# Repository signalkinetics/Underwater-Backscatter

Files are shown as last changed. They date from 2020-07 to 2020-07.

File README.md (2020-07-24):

# Underwater Backscatter

We present Piezo-Acoustic Backscatter (PAB), the first technology that enables backscatter networking in underwater environments.

Since wireless communication is the largest source of energy consumption for many underwater sensors, transitioning to
backscatter technology would eliminate the need for batteries which increase size and cost and require frequent replacement. Battery-free underwater sensors would enable us to **sense ocean conditions** (such as acidity, temperature, and bacteria content) over extended
periods of time and understand how they correlate with **climate change**. Scientists may attach these sensors to marine animals
and use them to **understand migration and habitat patterns**. Such sensors may even be **used in space missions to search for life** in the recently discovered subsurface oceans of Saturn’s moon, Titan. More generally, underwater battery-free sensors can be leveraged in
many long-term ocean applications such as **naval deployments, oil spill monitoring, and scientific exploration**

A PAB system consists of an acoustic projector (transmitter), a hydrophone (receiver), and a battery-free PAB sensor (which is essentially a piezoceramic transducer). When the projector transmits acoustic signals underwater, a PAB sensor harvests energy from these signals and powers up a microcontroller which controls the logic for backscatter. The PAB sensor then communicates by modulating the reflections of ambient sound signals. In particular, it can transmit a ‘0’ bit by absorbing the incoming energy, and a ‘1’ bit by reflecting the impinging acoustic signal. It can switch between the reflective and absorptive states by modulating the voltage across the piezoelectric interface, which in turn determines its vibration amplitude (i.e., reflection). The hydrophone receives the acoustic signals, senses changes in the amplitude due to reflection, and decodes these changes to recover the transmitted messages. In our system, we use PWM signals to trasmit data on the downlink and FM0 modulation  to send data on the uplink channel.

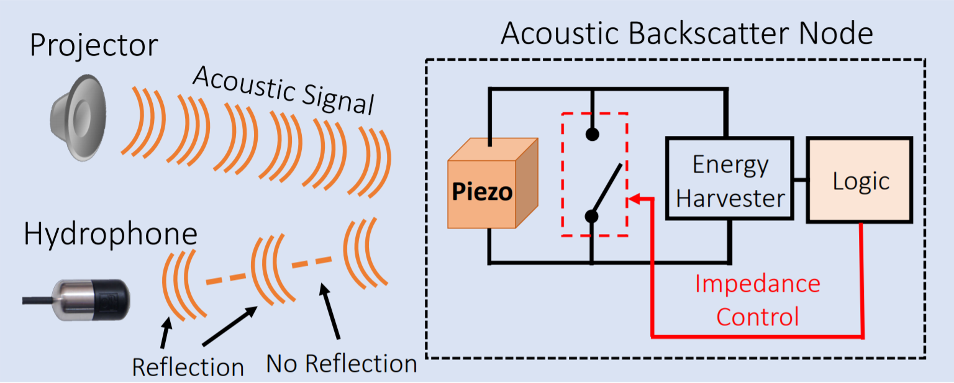
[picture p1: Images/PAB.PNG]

**PAB System Design**

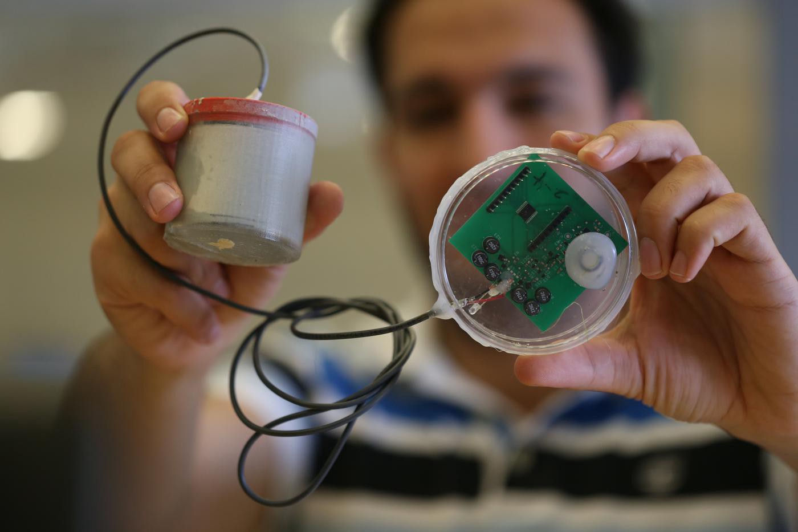
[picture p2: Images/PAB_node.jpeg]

**PAB sensor node**

# Contents

**MATLAB Rx Files/** - MATLAB code files for decoding the recieved FM0 signal.

**MATLAB Tx Files/** - MATLAB code files for transmitting a PWM acoustic signal.

**MCU code/** - C++ code for microcontroller (which controls backscatter logic).

**PCB Eagle Schematic/** - Circuit design for PCB which is connected to the PAB node.

**SolidWorks 3D Models/** - 3D printing models for mold, transducer caps and washers.

**PAB Tutorials/** - Detailed tutorials for fabricating PAB nodes and setting up the PAB system.

# Getting Started
The best way of manufacturing the PAB system is to first build the system hardware and then to work on the software part. There are several files in the "PAB Tutorials" folder which will guide you to build the system. To manufacture a PAB node, you would need a piezocermaic cylinder (we recommend ordering them from Steminc) and then 3D printing the remaining parts for assembly (SolidWorks 3D Models/). You would also need to connect wires to the inner and outer surface of the piezoceramic cylinder which will be used later to connect the PAB node to a custom made PCB with a microcontroller (PCB Eagle Schematic/). You can use the MCU code files to implement the backscatter logic in the microcontroller (MCU code/). Finally, you will need a piezoceramic transmitter and a hydrophone to transmit and receive signals respectively. We used MATLAB code to send data on the downlink and to decode the backscattered messages on the uplink (MATLAB Tx Files/, MATLAB Rx Files/)

# PAB Hardware Design
To fabricate a PAB node, you will need to get a piezoceramic cylinder and you would also need polyurethane resin (we recommend using WC-575A/B from BJP enterprise) for casting purposes. Once you have soldered wires on both sides of the piezoceramic cylinder, you would need to enclose it using 3D printed caps (with laser-cut rubber washers and screw) and then place it inside a 3D printed mold for casting (you can open the 3D models by installing the latest version of SolidWorks software). Finally you can cure the entire structure by placing it inside a pressure chamber at 4psi for at least 9 hours (see PAB tutorials for more details).

You would also need to print the PCB and populate it with all the necessary circuit components. The PCB circuit layout along with cicuit component specifications can be opened using the open source Eagle software by Autodesk (PCB Eagle Schematic/). The PCB needs to be connected to the two terminals of the potted piezoceramic cylinder node to complete the fabrication process of a PAB backscatter sensor. As a final step, you can program the MCU on the PCB by compiling the C++ code "main.c" on the microcontroller (MCU code/).

**Congratulations!** You have succesfully built a fully working, battery-free PAB sensor!

# PAB Transciever
To communicate with the PAB sensor you would need to send PWM acoustic pulses using the MATLAB code in "MATLAB Tx Files/" . To achieve this, you can simply fabricate a fully-potted piezoceramic transducer (i.e. omit the caps, washers and screws before casting) and use it as a projector. Connect the two leads of this transducer to the output of an amplifier (we recommend using Xli2500 Two-channel 750W power amplifier) and send the PWM signals by connecting the input terminals of the amplifier to a laptop using a audio jack. To deocde data on the uplink, you can simply use Audacity software to record the received sound pulses using a H2A Hydrophone and later you can decode this data offline by running "Main_Rx.m" in "MATLAB Rx Files/"

We hope that you will enjoy fabricating and deploying this PAB system in new and exciting applications. 

**Good Luck and Happy Back-scattering! :smiley:**

# Acknowledgement

**Advisor/PI:** Fadel Adib.

**Authors:** Sayed Saad Afzal, Osvy Rodriguez, Reza Gaffarivardavagh.

**Collaborators:** JunSu Jang, Jose Muguira Iturralde.

**For in-depth information on how PAB works:** 

Paper: [**Underwater Backscatter Networking**](https://www.media.mit.edu/projects/oceans/overview/), JunSu Jang and Fadel Adib [*ACM SIGCOMM'19*](https://conferences.sigcomm.org/sigcomm/2019/), Beijing, China, August 2019.

Demo Video: [Taking our ocean's pulse: Underwater Backscattering Networking](https://www.youtube.com/watch?v=zC3HaY6YJLY)

Presentation Video: [SIGCOMM 2020 talk](https://dl.acm.org/ft_gateway.cfm?id=3342091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)

# Citation
```
@incollection{jang2019underwater,
  title={Underwater backscatter networking},
  author={Jang, Junsu and Adib, Fadel},
  booktitle={Proceedings of the ACM Special Interest Group on Data Communication},
  pages={187--199},
  year={2019}
}

@incollection{gaffarivardavagh2020ultra-wideband,
  title={Ultra-Wideband Underwater Backscatter via Piezoelectric Metamaterials},
  author={Gaffarivardavagh, Reza and Afzal, Sayed Saad and Rodriguez, Osvy and Adib, Fadel},
  booktitle={Proceedings of the ACM Special Interest Group on Data Communication},
  year={2020}
}

```

Shield: [][cc-by-nc-sa]

This work is licensed under a
[Creative Commons Attribution-NonCommercial-ShareAlike 4.0 International License][cc-by-nc-sa].

[][cc-by-nc-sa]

[cc-by-nc-sa]: http://creativecommons.org/licenses/by-nc-sa/4.0/
[cc-by-nc-sa-image]: https://licensebuttons.net/l/by-nc-sa/4.0/88x31.png
[cc-by-nc-sa-shield]: https://img.shields.io/badge/License-CC%20BY--NC--SA%204.0-lightgrey.svg

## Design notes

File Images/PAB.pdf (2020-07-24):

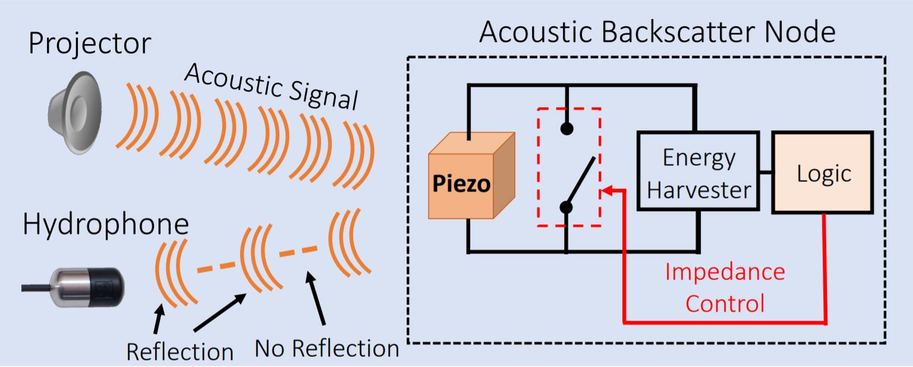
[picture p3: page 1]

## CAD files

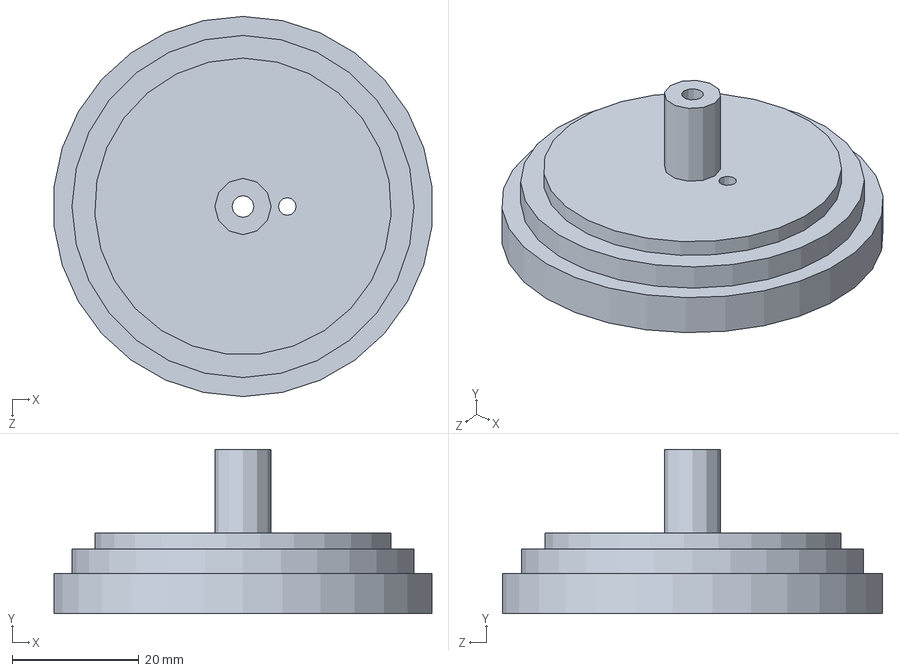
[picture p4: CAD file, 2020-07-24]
SolidWorks 3D Models/Transducer_Base_Single_Ring_For_Printing.SLDPRT
59.7 x 25.9 x 60.0 mm

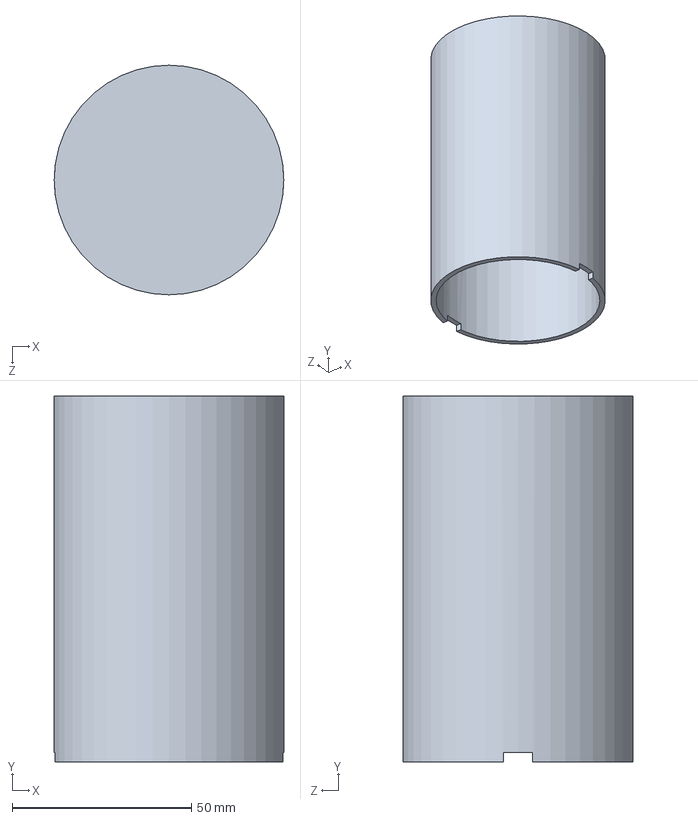
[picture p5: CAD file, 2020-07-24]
SolidWorks 3D Models/Mold_mod.SLDPRT
64.0 x 102.0 x 64.0 mm

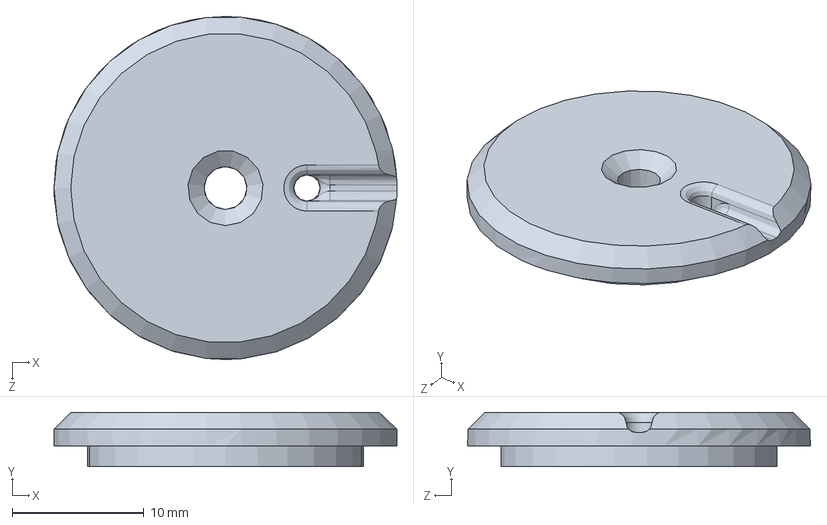
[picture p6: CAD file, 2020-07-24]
SolidWorks 3D Models/Transducer_Cap (1).SLDPRT
26.0 x 4.13 x 26.0 mm

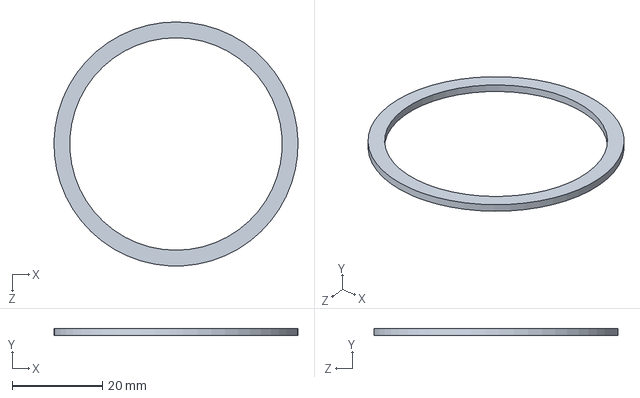
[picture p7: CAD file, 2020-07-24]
SolidWorks 3D Models/Washer.SLDPRT
54.0 x 1.59 x 54.0 mm

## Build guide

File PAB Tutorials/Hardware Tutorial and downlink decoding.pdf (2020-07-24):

Hardware Tutorial:

1- Energy Harvesting Unit

Let’s start by building the harvesting unit which is composed of two main parts the voltage multiplier and a supercapacitor to store the energy. The output of the voltage multiplier is a DC rectified and multiplied version of the incoming signal. In our design we used a fourstage voltage multiplier with this architecture.

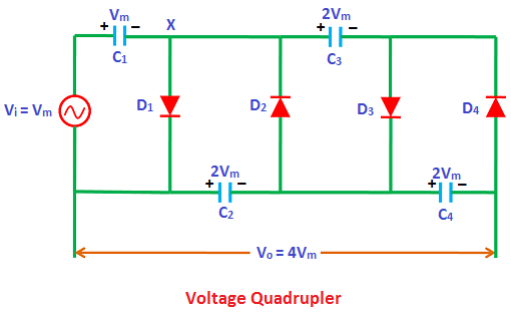
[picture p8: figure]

Fig1: Single ended voltage multiplier

Link for more information on voltage multipliers: https://www.physics-and-radio-electronics.com/electronic-devices-andcircuits/rectifier/voltagemultipliers-voltagedoubler-tripler-quadrupler.html (https://www.physics-and-radio-electronics.com/electronic-devices-and-circuits/rectifier/voltagemultipliers-voltagedoubler-tripler-quadrupler.html)

Note1: The DC voltage at the output of the voltage regulator is given by:

Vo = N*(Vmax-Vth)

Where N is the number of stages of the voltage multiplier (4 in our case), Vmax is the amplitude of the incoming signal, and Vth is the threshold voltage of the diodes being used.

Note2: The DC output of the voltage multiplier can be negative or positive depending on the orientation of the diodes.

Note3: The voltage multiplier acts as an envelope detector (low-pass filter); thus, when transmitting a PWM signal the output of the voltage regulator will look like the envelope of a sinusoidal signal that turns on and off. Like in the image below. If lower capacitances in the voltage multiplier are used the discharging time can be decreased; however, this will also cause a small ripple to appear.

Note4: The schematic in Fig.1 shows a single ended voltage multiplier for simplicity. However, since the output of the piezo electric is differential in our circuit design, we have a differential voltage multiplier which also includes a mirror image of the schematic in Fig1. (You will find the full architecture in our PCB layout)

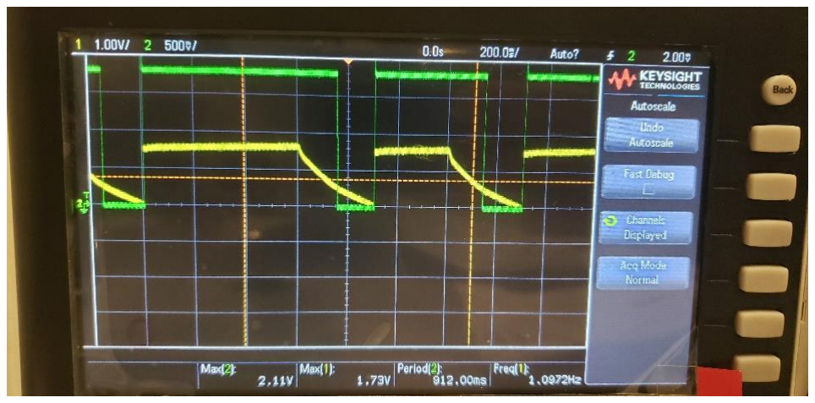
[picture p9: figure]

Fig2: Yellow curve is the PWM signal after the voltage regulator. Green curve is the Schmitt triggered version of the yellow signal.

Connect the output of the rectifier to the supercapacitor (10000 pF) via two diodes in series like the image below.

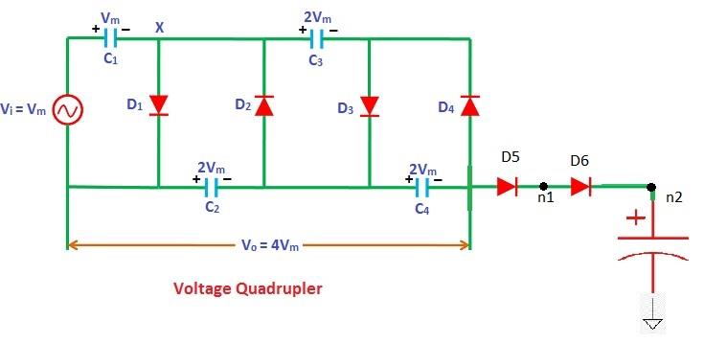
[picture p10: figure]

2- Downlink Decoder

The decoder in our circuit is composed by a level shifter (TXB0302) fig4, which incorporates a Schmitt Trigger, and a pull-down resistor that is turned on by the MCU(MSP430G2553) when decoding is desired. This part of the circuit converts the output of the PWM signal into a nice clean square wave that can be decoded by the MCU. The reason for the pull-down resistor is to fasten the discharging time of the voltage regulator’s capacitors and improve

SNR. The level shifter shifts the signal to a point where that can be detected for the MCU. The output of the level shifter is the green curve in fig2.

Note1: The used MCU incorporates a Schmitt trigger at its input; thus, we could have used only a level shifter.

Note2: The level shifter output is shifted up to the voltage fed into VccB

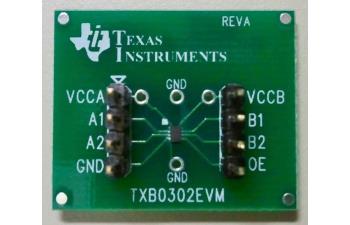
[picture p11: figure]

Fig4: Level shifter TXB0302

Connections:

The level shifter is connected to the rest of the circuit as follows. The junction between diodes D5 and D6 is connected to both VccA and A1. VccB is connected to the output of the voltage regulator. B1 is the output of the level shifter so it is connected the pin 1.1 of our MCU. The OE pin is connected to any pin of our MCU that outputs a constant voltage when it is on and ready to decode. Finally, GND is connected to ground.

Note: The output enable should also be connected to GND via a 47Kohm resistor as suggested by Texas Instruments.

3- Voltage Regulator:

A voltage regulator is needed in our circuit in order to drive the MCU and level shifter with a constant and stable voltage. The voltage regulator used was a lp5900sd(1.8V) because we want to exploit our MCU capability to operate when driven at its minimum voltage of 1.6V.

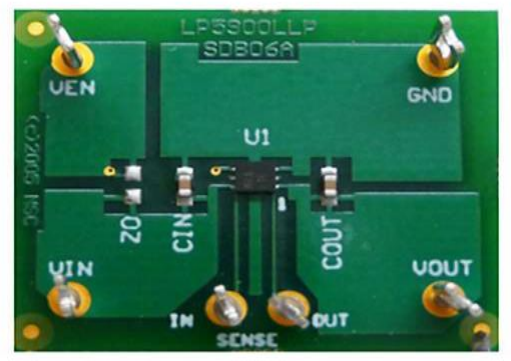
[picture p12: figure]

Fig5: lp5900SD

Connections:

The voltage regulator is connected to the rest of the circuit as follows. Ven and Vin are both connected to the positive end of the supercapacitor. Vout is connected to the VccB pin of the level shifter and to the 3.3V pin of our MCU. Finally, GND is connected to ground.

Note1: Vout and Vin both need a 0.47nF bypass capacitor as described in the image below.

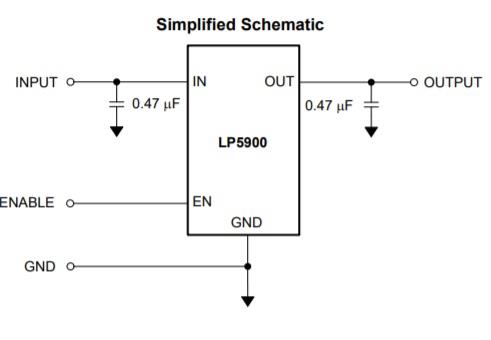
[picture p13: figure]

Fig6: LP5900 connections

Note2: If the Ven is higher than 1.2 V the LP5900 will activate and it will saturate at approximately 1.8V when the Vin reaches values higher than 1.8V.

4- Backscatter switches:

Note1: The backscatter switches consist of two N-channel MOSFETs connected in series sharing a common ground. Their sources are connected to each other and to ground. Their gates are connected to the same pin of the MCU (pin 1.0) which turns them on and off. Switching between reflective and absorptive state. The drain of each MOSFET is connected to one terminal of the piezo.

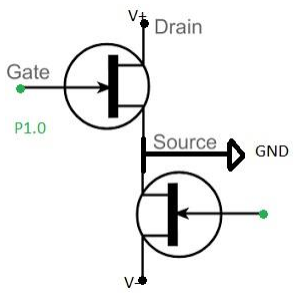
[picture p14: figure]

5- Impedance Matching Network:

The piezo electric source has a characteristic impedance. Thus, in order to ensure maximum power transfer to our circuit we added an impedance matching network. We used an L shape network composed by only inductors and capacitors. We used the E4990A Impedance analyzer to measure the impedance of the source and load.

The PCB design is shown below:

PCB layout link:

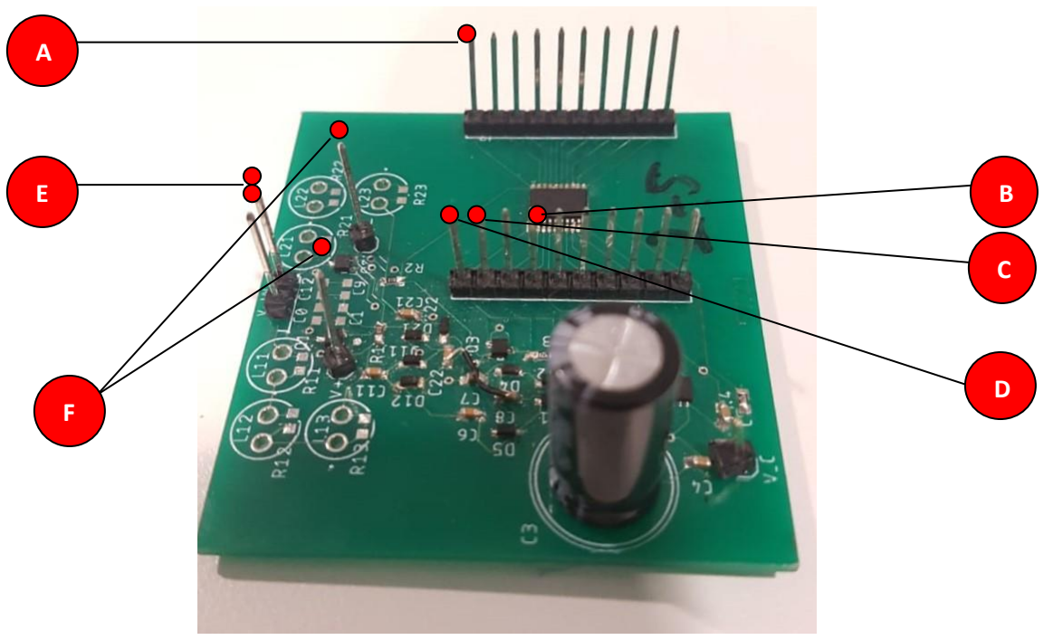
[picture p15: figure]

Note that the PCB does not include the impedance matching circuit, but still the PCB can power up the MCU and control the switching of MOSFETs if the super-capacitor can charge up to at least 2.5V from the differential PWM input signal.

The details for inputs and outputs are given below:

A

B

C

D

E

F

This pin is the common ground for the entire PCB. Use this pin as a reference when measuring voltages across different components using oscilloscope.

This pin will receive the envelop of the PWM signal in the form of a square wave which is the output of the level-shifter. If this pin shows a different waveform then check the level shifter and see if it is working properly.

This pin will output the signal which will control the switching of mosfets. The output of this pin depends entirely on the decoding algorithm in the MCU and also on the input from pin “B”

This pin is the VCC input to the MCU. If the voltage on this pin is lower than 1.8V then the MCU will not power up.

These set of pins will be used to input the differential PWM signal from the piezoelectric device. Use these pins only after you have populated the PCB will all the components which are required for impedance matching

These set of pins can also be used to input the differential PWM signal. You can use these pins even if you don’t have the impedance matching circuit

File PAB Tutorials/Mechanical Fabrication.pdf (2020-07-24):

Mechanical Fabrication of Nodes:

What you will need:

1- Steminc ceramic cylinder
2- Pressure pot
3- PLA printing material
4- polyurethane WC-575A mixture from BJB enterprises 5- Rubber sheet
6- Screws and nuts
7- Access to 3D printer, soldering station, laser cutter

The main component of our transducer is a piezoelectric cylinder. We purchased a ceramic cylinder (fig. 1) from Steminc with an in-air resonance frequency of 17 kHz, a radius of 2.5 cm, and a length of 4 cm.

Purchase link :https://www.steminc.com/PZT/en/piezo-ceramic-cylinder-541x47x40mm-17-khz

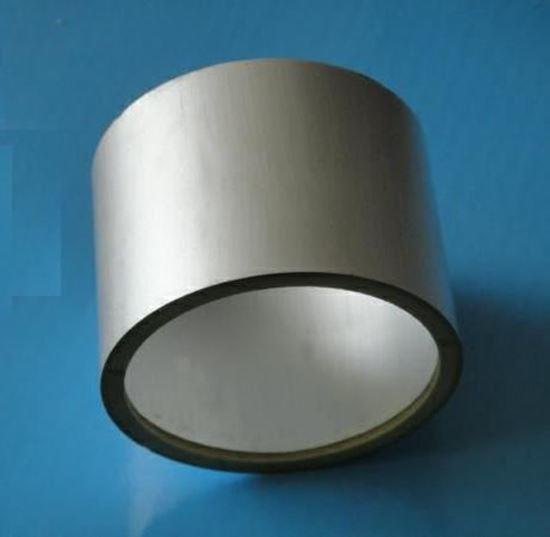
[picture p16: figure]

Fig. 1 Ceramic cylinder

Procedure:

1- First, we soldered two wires to the two electrodes of the piezoelectric ceramic (i.e., the inner and outer surfaces of the cylinder) as represented below.

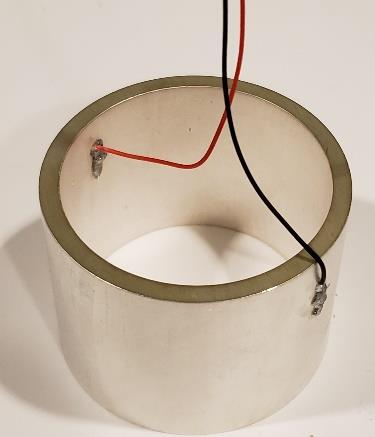
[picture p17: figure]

Fig. 2

2- We 3D printed the base and the top cap from as well as a cylindrical mold to house the ceramic cylinder and encapsulation polymer.

Add the models for 3d printing

3-Then, we laser cut rubber washers and placed them on the top and bottom of the cylinder, then placed it on a base and added a top cap.

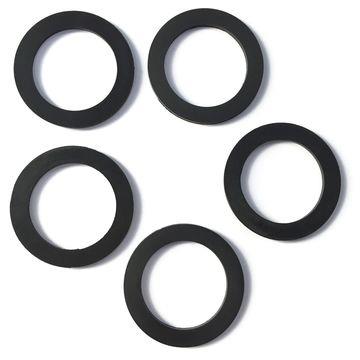
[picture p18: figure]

Fig3. Rubber washers

4- The setup is held tight using a screw and locking nut, then placed inside the mold.

Link for screws and nuts:
https://www.homedepot.com/p/Everbilt-M3-5-Stainless-Steel-Metric-Hex-Nut-2-Piece-per-Bag-842318/204836105 (https://www.homedepot.com/p/Everbilt-M3-5-Stainless-Steel-Metric-Hex-Nut-2-Piece-per-Bag-842318/204836105)

https://www.homedepot.com/p/Everbilt-M3-0-5-x-20-mm-Phillips-Pan-Head-Stainless-Steel-Machine-Screw-2-Pack-842738/204283765 (https://www.homedepot.com/p/Everbilt-M3-0-5-x-20-mm-Phillips-Pan-Head-Stainless-%20%20Steel-Machine-Screw-2-Pack-842738/204283765)

5- Finally, we prepared the encapsulation polymer, we used the polyurethane WC-575A/B mixture from BJB enterprises. The mix ratio by volume is A-100 B-94. We placed the mixture in a pressure pot at 60 (4atm) psi for at least 9 hours.

Pressure pot link: https://www.smooth-on.com/products/pressure-chamber/

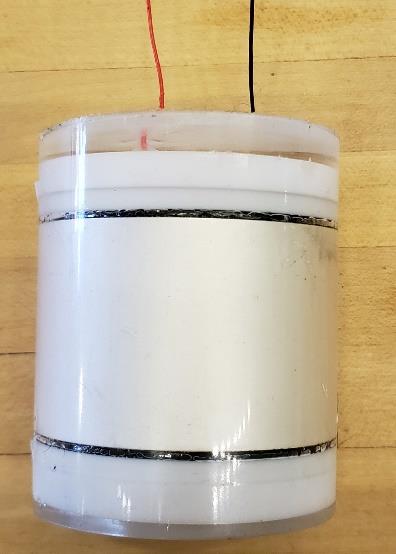
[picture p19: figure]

Fig 4. Final result

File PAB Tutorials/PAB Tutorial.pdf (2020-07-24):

# Underwater Backscatter Networking Tutorial

Mechanical Fabrication of Nodes:

What you will need:

1- Steminc ceramic cylinder
2- Pressure pot
3- PLA printing material
4- polyurethane WC-575A mixture from BJB enterprises 5- Rubber sheet
6- Screws and nuts
7- Access to 3D printer, soldering station, laser cutter

The main component of our transducer is a piezoelectric cylinder. We purchased a ceramic cylinder (fig. 1) from Steminc with an in-air resonance frequency of 17 kHz, a radius of 2.5 cm, and a length of 4 cm.

Purchase link :https://www.steminc.com/PZT/en/piezo-ceramic-cylinder-541x47x40mm-17-khz


Fig. 1 Ceramic cylinder

Procedure:

1- First, we soldered two wires to the two electrodes of the piezoelectric ceramic (i.e., the inner and outer surfaces of the cylinder) as represented below.

Fig. 2


2- We 3D printed the base and the top cap from as well as a cylindrical mold to house the ceramic cylinder and encapsulation polymer.

3-Then, we laser cut rubber washers and placed them on the top and bottom of the cylinder, then placed it on a base and added a top cap.


Fig3. Rubber washers

4- The setup is held tight using a screw and locking nut, then placed inside the mold.

Link for screws and nuts:

https://www.homedepot.com/p/Everbilt-M3-5-Stainless-Steel-Metric-Hex-Nut-2-Piece-per-Bag-842318/204836105 (https://www.homedepot.com/p/Everbilt-M3-5-Stainless-Steel-Metric-Hex-Nut-2-Piece-per-Bag-842318/204836105)

https://www.homedepot.com/p/Everbilt-M3-0-5-x-20-mm-Phillips-Pan-Head-Stainless- Steel-Machine-Screw-2-Pack-842738/204283765 (https://www.homedepot.com/p/Everbilt-M3-0-5-x-20-mm-Phillips-Pan-Head-Stainless-%20%20Steel-Machine-Screw-2-Pack-842738/204283765)

5- Finally, we prepared the encapsulation polymer, we used the polyurethane WC-575A/B mixture from BJB enterprises. The mix ratio by volume is A-100 B-94. We placed the mixture in a pressure pot at 60 (4atm) psi for at least 9 hours.

Pressure pot link: https://www.smooth-on.com/products/pressure-chamber/

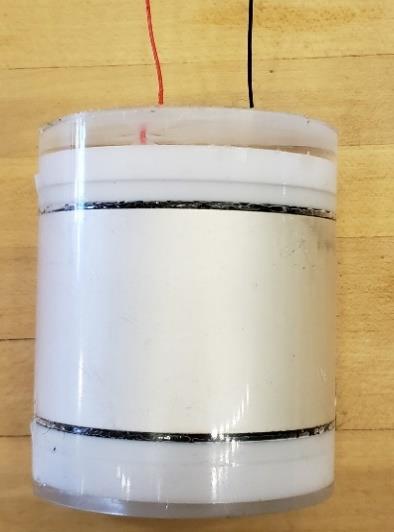
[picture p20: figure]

Fig 4. Encapsulated transducer

Hardware Tutorial

1- Energy Harvesting Unit

Let’s start by building the harvesting unit which is composed of two main parts the voltage multiplier and a supercapacitor to store the energy. The output of the voltage multiplier is a DC rectified and multiplied version of the incoming signal. In our design we used a four-stage voltage multiplier with this architecture.


Fig1: Single ended voltage multiplier

Link for more information on voltage multipliers: https://www.physics-and-radio-electronics.com/electronic-devices-and-circuits/rectifier/voltagemultipliers-voltagedoubler-tripler-quadrupler.html (https://www.physics-and-radio-electronics.com/electronic-devices-and-circuits/rectifier/voltagemultipliers-voltagedoubler-tripler-quadrupler.html)

Note1: The DC voltage at the output of the voltage regulator is given by:

Vo = N*(Vmax-Vth)

Where N is the number of stages of the voltage multiplier (4 in our case), Vmax is the amplitude of the incoming signal, and Vth is the threshold voltage of the diodes being used.

Note2: The DC output of the voltage multiplier can be negative or positive depending on the orientation of the diodes.

Note3: The voltage multiplier acts as an envelope detector (low-pass filter); thus, when transmitting a PWM signal the output of the voltage regulator will look like the envelope of a sinusoidal signal that turns on and off. Like in the image below. If lower capacitances in the voltage multiplier are used the discharging time can be decreased; however, this will also cause a small ripple to appear.

Note4: The schematic in Fig.1 shows a single ended voltage multiplier for simplicity. However, since the output of the piezo electric is differential in our circuit design, we have a differential voltage multiplier which also includes a mirror image of the schematic in Fig1. (You will find the full architecture in our PCB layout)


Fig2: Yellow curve is the PWM signal after the voltage regulator. Green curve is the Schmitt triggered version of the yellow signal.

Connect the output of the rectifier to the supercapacitor (10000 pF) via two diodes in series like the image below.

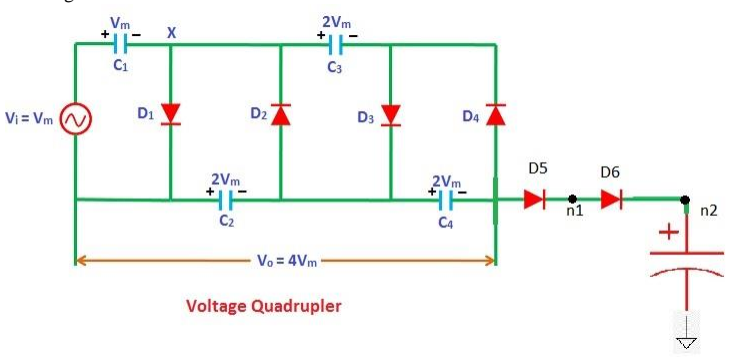
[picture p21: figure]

2- Downlink Decoder

The decoder in our circuit is composed by a level shifter (TXB0302) fig4, which incorporates a Schmitt Trigger, and a pull-down resistor that is turned on by the MCU(MSP430G2553) when decoding is desired. This part of the circuit converts the output of the PWM signal into a nice clean square wave that can be decoded by the MCU. The reason for the pull-down resistor is to fasten the discharging time of the voltage regulator’s capacitors and improve SNR. The level shifter shifts the signal to a point where that can be detected for the MCU. The output of the level shifter is the green curve in fig2.

Note1: The used MCU incorporates a Schmitt trigger at its input; thus, we could have used only a level shifter.

Note2: The level shifter output is shifted up to the voltage fed into VccB

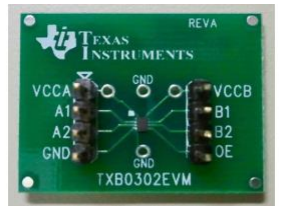
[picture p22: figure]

Fig4: Level shifter TXB0302

Connections:

The level shifter is connected to the rest of the circuit as follows. The junction between diodes D5 and D6 is connected to both VccA and A1. VccB is connected to the output of the voltage regulator. B1 is the output of the level shifter so it is connected the pin 1.1 of our MCU. The OE pin is connected to any pin of our MCU that outputs a constant voltage when it is on and ready to decode. Finally, GND is connected to ground.

Note: The output enable should also be connected to GND via a 47Kohm resistor as suggested by Texas Instruments.

3- Voltage Regulator:

A voltage regulator is needed in our circuit in order to drive the MCU and level shifter with a constant and stable voltage. The voltage regulator used was a lp5900sd(1.8V) because we want to exploit our MCU capability to operate when driven at its minimum voltage of 1.6V.


Fig5: lp5900SD

Connections:

The voltage regulator is connected to the rest of the circuit as follows. Ven and Vin are both connected to the positive end of the supercapacitor. Vout is connected to the VccB pin of the level shifter and to the 3.3V pin of our MCU. Finally, GND is connected to ground.

Note1: Vout and Vin both need a 0.47nF bypass capacitor as described in the image below.


Fig6: LP5900 connections

Note2: If the Ven is higher than 1.2 V the LP5900 will activate and it will saturate at approximately 1.8V when the Vin reaches values higher than 1.8V.

4- Backscatter switches:

Note1: The backscatter switches consist of two N-channel MOSFETs connected in series sharing a common ground. Their sources are connected to each other and to ground. Their gates are connected to the same pin of the MCU (pin 1.0) which turns them on and off. Switching between reflective and absorptive state. The drain of each MOSFET is connected to one terminal of the piezo.


The PCB design is shown below:

PCB layout link:

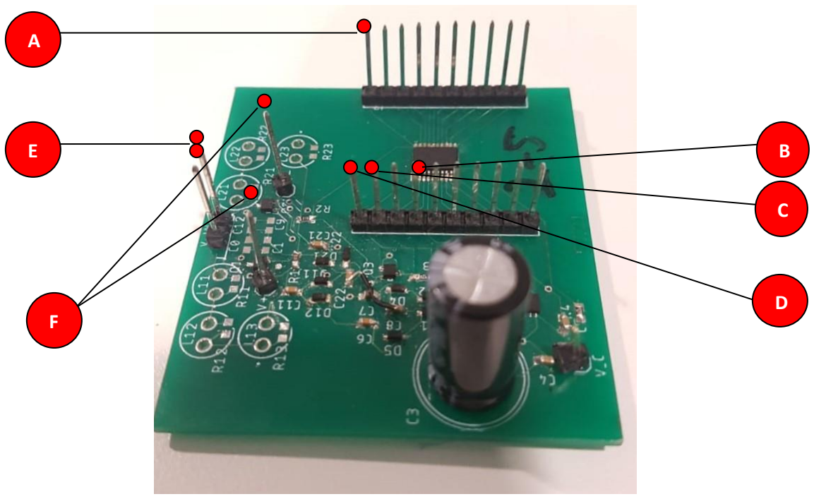
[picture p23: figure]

Note that the PCB does not include the impedance matching circuit, but still the PCB can power up the MCU and control the switching of MOSFETs if the super-capacitor can charge up to at least 2.5V from the differential PWM input signal.

The details for inputs and outputs are given below:

A

B

C

D

E

F

This pin is the common ground for the entire PCB. Use this pin as a reference when measuring voltages across different components using oscilloscope.

This pin will receive the envelop of the PWM signal in the form of a square wave which is the output of the level-shifter. If this pin shows a different waveform then check the level shifter and see if it is working properly.

This pin will output the signal which will control the switching of mosfets. The output of this pin depends entirely on the decoding algorithm in the MCU and also on the input from pin “B”

This pin is the VCC input to the MCU. If the voltage on this pin is lower than 1.8V then the MCU will not power up.

These set of pins will be used to input the differential PWM signal from the piezoelectric device. Use these pins only after you have populated the PCB will all the components which are required for impedance matching

These set of pins can also be used to input the differential PWM signal. You can use these pins even if you don’t have the impedance matching circuit

Transmitter (Tx)

What you would need:

1- Our in-house built transducer
2- Laptop or desktop computer with audio jack output 3- Xli2500 Two-channel 750W power amplifier

Note:

The transmitted signal is generated using MATLAB, we first transmit a pure sine at around 17kHz the resonant frequency of our transducer. Secondly, we employ pulse width modulation (PWM) where the ‘1’ bit is twice as long as the ‘0’ bit.

PAB (Tx) MATLAB code

%The transmission consists of two stages: energy harvesting stage and
%communication stage: During the energy harvesting stage we transmit a pure
%sinusoidal signal and during the communication stage we transmit a PWM
%that encodes 1's and 0's (being a 1 twice longer that a 0). Finally, we
%transmit again a pure sinusoidal that will be backscattered by the node.

% Generate purely sinusoidal
f = 15000; %15Khz
Fs = 44100; %Sampling frequency ts = 1/Fs;
T | = 10; % Generate 10 seconds
t | = 0:ts:T;
signal = sin(2*pi*f.*t);
%%%%%%%%%%%%%%%%%%%%%%%%

%Generate bits
preamble = [1 0 1 1 0 1 1 1 0 1 0 0 1 0 0 0 1 0 1 0]; bit1 = repmat(1,1,2*9000);
bit0 = repmat(1,1,9000);
zero = repmat(0,1,9000);

sq = [];
for bit = preamble

if bit == 1
sq = [sq bit1 zero];

elseif bit == 0
sq = [sq bit0 zero];

end
end
%modulated signal
PWM = sq(1:end-length(zero)+1).*signal; %%%%%%%%%%%%%%%%%%%%%%%%

%Charge the PAB node and then transmit preamble

sound(signal, Fs);
pause(12) %wait for 12 seconds
sound(PWM, Fs);
pause(12)
sound(signal,Fs)

Receiver (Rx)

What you would need:

1- H2A Hydrophone (Fig. 1)

2- Laptop or desktop computer with audio jack input

3- Audacity software

4- Our MATLAB decoder

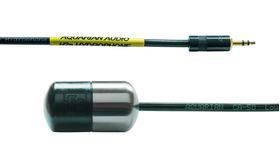
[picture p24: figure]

Fig. 1

Link:

https://www.aquarianaudio.com/h2a-hydrophone.html

https://www.audacityteam.org/

MATLAB decoder:

Our decoder identifies the different transmitted frequencies on the downlink using FFT and peak detection. It then down-converts the signals to baseband by multiplying each of them with its respective carrier frequency. The receiver then employs a Butterworth filter on each of the receive channels to isolate the signal of interest and reduce interference from concurrent transmissions. Subsequently, it performs standard packet detection and carrier frequency offset (CFO) correction using the preamble. Finally, it employs a maximum likelihood decoder to decode the FM0 decoded bits.

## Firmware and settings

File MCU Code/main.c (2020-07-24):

// Underwater Acoustic Backscatter MCU
//
// Goal: Receive and decode a known query. Upon successful
//       decoding, backscatter signal by toggling between
//       reflective and non-reflective state
//
// Communication: FM0 (varying length of reflection followed by
//                     no a period of no reflection)
//                bit 1: long reflection (2*BIT_PERIOD)
//                bit 0: short reflection (BIT_PERIOD)
//
// Pin Layout
// Pin0: Controls the transistors to control
//       reflective/non-reflective state
// Pin2: Rectified singal input whose rising edge is
//       detected every clock cycle
// Pin3: Toggling at every detected rising edge (debug)
// Pin6: Swtich on the pull-down resistor to control
//       the receiving/transmitting mode

#include <msp430.h>
#include <stdint.h>

#define QUERY_LEN 9
#define PREAMBLE_LEN 20
#define TX_LEN 32
#define HALF_CYCLE 25
#define BIT_PERIOD 500
#define QUERY_FLIP_PERIOD 3000

uint16_t bit_start = 0, gap=1;
uint16_t now, bit, i;
uint8_t rx_fifo = 0, offset = 0, query = 0b10110100, mask=0xFF;
uint32_t tx_byte;
uint32_t preamble1 = 0b10110111010010001010;
uint32_t training = 0b00000000000000000000;
uint32_t data_byte = 0b10110100101101001011010010110100;
uint32_t data_byte2 = 0b10101010101010101010101010101010;
uint32_t data_byte3 = 0b11110000110010100000111100110101;
uint32_t bit_count;
uint8_t temp, state_AB, clk, state;
int cycle;

void printf(char *, ...);
void RX_Ready (void);
void TX_Byte(void);
void Preamble_Byte (void);

inline static void Clock_init(void);
//Sets up two clocks; one normal and another low-frequency low-power clock in order to use them 
//in the different states of the MCU

int main(void)
{
     WDTCTL = WDTPW | WDTHOLD;                    // Stop WDT
     Clock_init();                                // Initialize the clocks

    // Configure GPIO
    P1DIR |= BIT0 + BIT4 + BIT3; // BIT3                 // Set pins to outputs
    P1OUT &= ~(BIT0 + BIT3);                             // piezo and load are connected
    P1OUT |=  BIT4; //BIT3                        // debug and ready to receive
    P1SEL = BIT2;                                 // Setup for clock interrupts on pin2

    TACTL = TASSEL_1 | MC_2 | TACLR;              // Sets up timer A.
												  //ACLK, continuous mode, clears timer A before starting, enable interrupt
	
												  
												  
												  
												  
	// Enter LPM3, enable interrupts

    cycle = 100;

    bit_count = PREAMBLE_LEN;
    // Send Preamble
    while (bit_count > 0) {

		for (i=0; i<cycle; i++) {};//Delays according to the cycle (in this case is 100)


		//In this piece of code you send a series of bits by toggling the device between the reflective/non-reflective states
		//You do this in a loop that last for as many bits as the preamble has.
		//BIT0 is the one in charge of toggling the device between the two modes
		//Most of the other variables are used for properly sending the desired preamble
        bit = (bit & 0) + clk & (preamble1 >> bit_count) & BIT0;
        state_AB = (((clk^(state_AB & BIT0)) & BIT0) << 1) + ((((~bit) & state_AB&BIT0)|((~clk)& state_AB&BIT0)|(clk&bit&(~(state_AB&BIT0))))&BIT0);
        temp = ((clk & BIT0) * ((state_AB & BIT1) >> 1) + ((~clk) & BIT0) * (state_AB & BIT0));
        P1OUT = (P1OUT & ~BIT0) + (temp & BIT0);
        clk = (~clk) & BIT0;
        bit_count -= clk;
    }

	//Sending another piece of information
    bit_count =200;
    while (bit_count > 0) {

        for (i = 0; i < cycle; i++) {};// Delay used according to the cycle(in this case is 100)
        bit = 1; 


        state_AB = (((clk^(state_AB & BIT0)) & BIT0) << 1) + ((((~bit) & state_AB&BIT0)|((~clk)& state_AB&BIT0)|(clk&bit&(~(state_AB&BIT0))))&BIT0);



        temp = ((clk & BIT0) * ((state_AB & BIT1) >> 1) + ((~clk) & BIT0) * (state_AB & BIT0));
        P1OUT = (P1OUT & ~BIT0) + (temp & BIT0);
        clk = (~clk) & BIT0;
        bit_count -= clk;

    }
    P1OUT &= ~BIT0;

//     sleep

}

// Set the MCU into receiving mode
void RX_Ready(void) {
    P1OUT &= ~(BIT0 + BIT1);//Puts BIT0 = 0 to toggle into receiving mode
    rx_fifo = 0;
    bit_count = 8;
    // Configure Timer_A
    TACCTL1 = SCS + CM_1 + CAP + CCIE + CCIS_0;
	//Timer A1
	//SCS = Capture Synchronize
	//CM_1 = Capture mode: 1- pos. edge
	//CAP = Capture mode: 1
	//CCIE = Capture/Compare Interrupt enable
	//CCIS_0 = Capture input select: 0 - CCIxA
}

// Set the MCU to transmitting mode
void TX_Byte(void) {
    state_AB = 0b00;
    clk = 1;
    bit_count = TX_LEN; //data    32
    tx_byte = data_byte2;//This is the transmitted data
    // Set timer interrupts
    TACCR1 = TAR + HALF_CYCLE;
    // Reconfigure Timer_A
    TACCTL1 = CM_0 + CCIE;
	//This configuration makes it not being in capture mode
	//but it has enabled interrupts in case new information is arriving
}

void Preamble_Byte(void) {
	//This function is used for transmitting the preamble
    state = 1;
    state_AB = 0b00;
    clk = 1;
    bit_count = PREAMBLE_LEN; // preamble
    tx_byte = preamble1; //training;
    // Set timer interrupts
    TACCR1 = TAR + HALF_CYCLE;
    // Reconfigure Timer_A
    TACCTL1 = CM_0 + CCIE;
}


// Timer0_A1 Interrupt Vector (TAIV) handler
#if defined(__TI_COMPILER_VERSION__) || defined(__IAR_SYSTEMS_ICC__)
#pragma vector=TIMER0_A1_VECTOR
__interrupt void TIMER0_A1_ISR(void)
#elif defined(__GNUC__)
void __attribute__ ((interrupt(TIMER0_A1_VECTOR))) TIMER0_A1_ISR (void)
#else
#error Compiler not supported!
#endif
{
    switch(__even_in_range(TA0IV,TA0IV_TAIFG))
    {
        case TA0IV_NONE:
            break;//In case of no interrupt pending just continue
        case TA0IV_TACCR1:
            // RX mode
            if(TACCTL1 & CAP) {
                now = TACCR1; // timestamp
                // we start measuring the duration of amplitude flip on the first
                // rising edge. Hence, we let the bit_count start at 9 instead of 8
                if (bit_count < 8) {
                    if ((TACCTL1 & BIT1) == 0) {
                        // Determine how long for a amplitude flip to determine bit received
                        bit = (now - bit_start) > QUERY_FLIP_PERIOD ? 1 : 0;
                        rx_fifo |= bit << bit_count;
                    } else { // There was a second capture unfortunately
                        TACCTL1 &= ~(BIT1);
                    }
                }
                // All the bits have been received
                if (bit_count == 0) {

                    // Compare the bits first
                    offset = 0;
                    while ((offset < QUERY_LEN) \
                            && ((rx_fifo & (mask >> offset)) != (query >> offset))) {
                        offset++;
                    }
                    // successful
                    if (offset == 0) {
                        P1OUT |= BIT3;
                        TACCTL1 &= ~CCIE;                  // All bits RXed, disable interrupts from capture
                        __bic_SR_register_on_exit(LPM3_bits); // CLear LPM3its to start transmitting
                    } else {
                    // failed
                        RX_Ready();
                    }
                }
                bit_count--;
                bit_start = now;
            // TX mode
            } else {
                TACCR1 += HALF_CYCLE;
                if (bit_count == 0 && clk == 1) {
                    state += 1;
                    if (state == 1) {
                        bit_count = PREAMBLE_LEN;
                        tx_byte = preamble1;
                    } else if(state == 2) {
                        bit_count = 1000; //TX_LEN;
                        tx_byte = data_byte2;
                    } else if (state > 2){
                        TACCTL1 &= ~CCIE;
                        __bic_SR_register_on_exit(LPM3_bits);
                    }
                }
                bit_count -= clk;
                if (state == 0) {
                    bit = 0;
                } else if (state == 1) {
                    bit = (bit & 0) + clk & (tx_byte >> bit_count) & BIT0;
                } else if (state == 2) {
                    bit = (bit ^ clk) & BIT0;
                }
                state_AB = (((clk^(state_AB & BIT0)) & BIT0) << 1) + ((((~bit) & state_AB&BIT0)|((~clk)& state_AB&BIT0)|(clk&bit&(~(state_AB&BIT0))))&BIT0);
                temp = ((clk & BIT0) * ((state_AB & BIT1) >> 1) + ((~clk) & BIT0) * (state_AB & BIT0));
                P1OUT = (P1OUT & ~BIT0) + (temp & BIT0);
                clk = (~clk) & BIT0;


                }
            TACCTL1 &= ~(BIT0);
            break;                               // CCR1 not used
        case TA0IV_TACCR2:
            break;                               // CCR2 not used
        case TA0IV_TAIFG:
            break;
        default:
            break;
    }

}

inline static void Clock_init(void)
{
    BCSCTL1 = CALBC1_1MHZ;              // Set Digitally Controlled Oscillator (DCO) to default of 1Mhz
    DCOCTL = CALDCO_1MHZ;			    // Set the DCO Register to 1 Mhz  (step & modulation)

    BCSCTL3 = LFXT1S_2;                // LFXT1 = VLO (Very Low-Power Low-Frequency Oscillator). Clock that uses little energy for functioning and no energy when off.
    IFG1 &= ~(OFIFG);                   // Clear OSCFault flag (Interrupt Flag Register)
}

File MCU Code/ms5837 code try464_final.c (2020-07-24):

//******************************************************************************
//  MSP430G2553 USCI_B0 I2C connection to ms5837-30BA 
//  ACLK = n/a, MCLK = SMCLK = BRCLK = default DCO = ~1.0MHz
//
//
//                                /|\  /|\
//                  MS5837        10k  10k   MSP430G2553
//                   slave         |    |      master
//             -----------------   |    |  -----------------
//            |       SDA       |<-|---+->|P1.7/UCB0SDA  
//            |                 |  |      |                 
//            |                 |  |      |             
//            |       SCLK      |<-+----->|P1.6/UCB0SCL     
//            |                 |         |                 
//
//******************************************************************************
#include <msp430.h>
#include <stdint.h>

#define NUM_BYTES_TX 1                  		
// FUNCTION RETURN VALUES
#define RET_SUCCESS		0
#define RET_FAIL			1
#define RET_FAIL_CALIB		4
#define RET_TIMEOUT		5

volatile int RXByteCtr, i;    	
volatile unsigned char RxBuffer[22];  			// Allocate 22 bytes of RAM
volatile int Rx_idx=0, Tx_idx=0;
volatile char TXByteCtr, RX = 0;
volatile char MSData[13]={0x1E,0xA0,0xA2,0xA4,0xA6,0xA8,0xAA,0xAC,0x4A,0,0x5A,0,0};
volatile char ret, receivedCrc, calculatedCrc;
volatile unsigned short buff[8];
volatile int NUM_BYTES_RX = 2;				// Received bytes = 2 for prom
volatile unsigned short sensorC[7];
volatile signed long D1=0, D2=0, dT, TEMP, PRESSURE; 
volatile signed long long SENS, pressure, temp, OFF;

void Setup_TX(void);
void Setup_TX1(void);
void Setup_RX(void);
void Transmit(void);
void Receive(void);
char unlockI2Cline(unsigned short maxLoops);
char isMS5837Available();
unsigned char crc4(volatile unsigned short n_prom[]);  


int main(void)
{
 	WDTCTL = WDTPW + WDTHOLD;              		// Stop WDT

	// Initialize P2 for ms5837 status
	P2DIR |= BIT0;                   				// P2.0 output
	P2OUT &= ~BIT0;							// Set P2.0 to low

  	P1SEL |= BIT6 + BIT7;                 		// Assign I2C pins to USCI_B0
  	P1SEL2|= BIT6 + BIT7;                  		// Assign I2C pins to USCI_B0
    
  	//Transmit process
  	Setup_TX(); 
  	Transmit(); 
	__delay_cycles(100000);  				// 100ms,Make sure reset done
  	while (UCB0CTL1 & UCTXSTP);

	for (i=0;i<7;i++)
	{	
  		Tx_idx++;
		Setup_TX1(); 
  		Transmit(); 
  		while (UCB0CTL1 & UCTXSTP);    			// Ensure stop condition got sent

  		//Receive process
  		Setup_RX();	
  		Receive();	
		__delay_cycles(10000);
  		while (UCB0CTL1 & UCTXSTP);     		// Ensure stop condition got sent
	}

	for (i=0;i<7;i++)
	{ 
		buff[i] = (RxBuffer[i*2]<<8) + RxBuffer[i*2+1]; 
		sensorC[i] = buff[i];
	}
	buff[7] = 0x0000;
	receivedCrc = ((buff[0] >> 8) >> 4) & 0x0F;	// Read received CRC
	calculatedCrc = crc4(buff);
	if(calculatedCrc != receivedCrc) ret = 33; 	// Compare with calculated CRC-4
	
	NUM_BYTES_RX = 3;
	for (i=0;i<2;i++)
	{	
  		Tx_idx++;
		Setup_TX1(); 
  		Transmit(); 
  		while (UCB0CTL1 & UCTXSTP);    		// Ensure stop condition got sent
		__delay_cycles(30000);		// ADC conversion > 18.08ms

		Tx_idx++;
		Setup_TX1(); 
  		Transmit(); 
  		while (UCB0CTL1 & UCTXSTP);    		// Ensure stop condition got sent

  		//Receive process
  		Setup_RX();	
  		Receive();	
		__delay_cycles(10000);
  		while (UCB0CTL1 & UCTXSTP);     	// Ensure stop condition got sent
	}
	
	__disable_interrupt();
	D1 = (signed long)RxBuffer[14]*256*256+ (signed long)RxBuffer[15]*256+ (signed long)RxBuffer[16];
	D2 = (signed long)RxBuffer[17]*256*256+ (signed long)RxBuffer[18]*256+ (signed long)RxBuffer[19];

	// Calculate compensated temperature and pressure
	dT = D2 - ((signed long)sensorC[5] * 256);
	OFF = ((signed long long)sensorC[2] * 65536) + (((signed long long)sensorC[4] * (signed long long) dT)/128);
	SENS = ((signed long long)sensorC[1] * 32768) + (((signed long long)sensorC[3] * (signed long long) dT)/256);
	temp = 2000 + ((signed long long)dT * (signed long long)sensorC[6])/8388608;
	TEMP = temp;
	pressure = (((signed long long)D1 * SENS / 2097152) - OFF) / 8192;
	PRESSURE = pressure;

	// If CRC correct AND 10degC < temperature < 30degC
	// AND 0.9bar < pressure < 2.1 bar (11m depth water)
	// toggle p2.0 at 1Hz for 5 times, otherwise p2.0 kept logic 0

	if ((receivedCrc == calculatedCrc) && (TEMP<3000 && TEMP>1000) && (PRESSURE<21000 && PRESSURE>9000)) 
	{	
		for (i=0;i<5;i++)
		{
			P2OUT |= BIT0 + BIT1;		// results correct
			__delay_cycles(500000);  		// p2.0 = 1 for 0.5s 
			P2OUT &= ~BIT0; P2OUT &= ~BIT1;	
        __delay_cycles(500000);  		// p2.0 = 0 for 0.5s
		}
	}	
	else P2OUT &= ~BIT0;			// ms5837 failed

	while(1){ __delay_cycles(100000);}		// put breakpoint here
}


unsigned char crc4(volatile unsigned short n_prom[])  
{
	int cnt; // simple counter
	unsigned int n_rem=0; 		// crc remainder
	unsigned char n_bit;
	n_prom[0]=((n_prom[0]) & 0x0FFF); 		// CRC byte is replaced by 0
	n_prom[7]=0;  				// Subsidiary value, set to 0
	for (cnt = 0; cnt < 16; cnt++) 		// operation is performed on bytes
	{ // choose LSB or MSB
		if (cnt%2==1) n_rem ^= (unsigned short) ((n_prom[cnt>>1]) & 0x00FF);
		else n_rem ^= (unsigned short) (n_prom[cnt>>1]>>8);
		for (n_bit = 8; n_bit > 0; n_bit--)
		{
			if (n_rem & (0x8000))  n_rem = (n_rem << 1) ^ 0x3000;
			else  n_rem = (n_rem << 1);
		}
	}
	n_rem= ((n_rem >> 12) & 0x000F); 		// final 4-bit remainder is CRC code
	return (n_rem ^ 0x00);
}
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

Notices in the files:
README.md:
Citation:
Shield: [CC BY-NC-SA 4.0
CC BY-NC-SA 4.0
